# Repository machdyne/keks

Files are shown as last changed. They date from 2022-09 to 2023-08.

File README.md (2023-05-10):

# Keks Game Console

Keks is a 32-bit FPGA-based video game console and computer designed as a fun educational platform for teaching and learning about computers, electronics, FPGAs and programming.

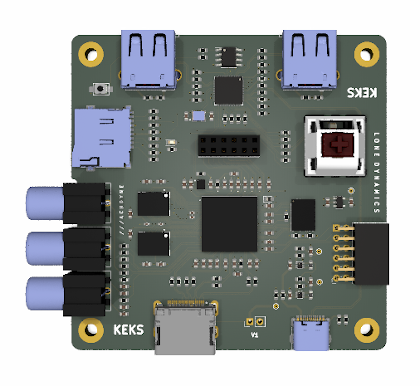
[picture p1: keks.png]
Keks Game Console


This repo contains schematics, PCB layouts, pinouts, firmware, gateware, documentation and a 3D printable case.

Find more information on the [Keks product page](https://machdyne.com/product/keks-game-console/).

## Blinky 

Building the blinky example requires [Yosys](https://github.com/YosysHQ/yosys), [nextpnr-ice40](https://github.com/YosysHQ/nextpnr) and [IceStorm](https://github.com/YosysHQ/icestorm).

Assuming they are installed, you can simply type `make` to build the gateware, which will be written to output/blinky.bin. You can then connect the USB-C port to your computer and use the latest version of [ldprog](https://github.com/machdyne/ldprog) to write the gateware to the device.

## Programming

The RP2040 firmware and FPGA SRAM can be programmed over the USB-C port.

Configure the FPGA SRAM:

```
$ ldprog -k -s blinky.bin
```

It should also be possible to transfer gateware and games to the MicroSD card over the USB-C port but this is not yet implemented.

## Games

* [pong](games/pong)

## Firmware

Keks ships with RP2040 [firmware](firmware) based on the [Müsli](https://github.com/machdyne/musli) firmware which allows it to communicate with [ldprog](https://github.com/machdyne/ldprog).

The firmware is responsible for initializing the system, [configuring and outputting the RP clock](https://www.raspberrypi.com/documentation/pico-sdk/hardware.html#hardware_clocks), configuring the FPGA and detecting USB HID events.

The RP clock (CLK\_RP) is 48MHz by default. Keks also has a 100 MHz oscillator on board (CLK\_100).

*The following description is still under development and may change.*

*If an inserted FAT-formatted MicroSD card contains a bitstream file in the root directory named GATEWARE.BIN it will be used to configure the FPGA after power-on.*

*The RP2040 firmware also acts as an SPI master and sends updates to the FPGA when the status of the gamepads/joysticks change.*

In addition to the 4 CSPI signals and CLK\_RP there are 6 other signals connected to both the RP2040 and the FPGA: RP\_TX, RP\_RX, and RP\_INT, CDONE, CRESET and BTN.

### Updating the Firmware

To build the latest firmware you will need to install the [Raspberry Pi Pico SDK](https://github.com/raspberrypi/pico-sdk).

Set the `PICO_SDK_PATH` environment variable to your SDK path.

```
$ git clone https://github.com/machdyne/keks
$ cd keks/firmware/keks
$ mkdir build
$ cd build
$ cmake ..
$ make
```

The firmware can then be updated by holding down the (small) BOOTSEL button, connecting the USB-C port to your computer, and then dragging and dropping a new UF2 file to the device filesystem.

## DDMI

See this [my_hdmi_device fork](https://github.com/machdyne/my_hdmi_device) for an example of outputting video on the DDMI port.

See this [SmolDVI fork](https://github.com/machdyne/SmolDVI) for another example of outputting video on the DDMI port.

## Pinouts

 * [DDMI](https://github.com/machdyne/ddmi)

## License

The contents of this repo are released under the [Lone Dynamics Open License](LICENSE.md) with the following exceptions:

- The KiCad design files contain parts of the [kicad-pmod](https://github.com/mithro/kicad-pmod) library which is released under the [Apache License, Version 2.0](https://www.apache.org/licenses/LICENSE-2.0.html).

- The KiCad design files may contain symbols and footprints released under other licenses; please contact us if we've failed to give proper attribution.

Note: You can use these designs for commercial purposes but we ask that instead of producing exact clones, that you either replace our trademarks and logos with your own or add your own next to ours.

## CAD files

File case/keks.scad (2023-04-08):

/*
 * Keks Case
 * Copyright (c) 2022 Lone Dynamics Corporation. All rights reserved.
 *
 * required hardware:
 *  - 4 x M3 x 20mm countersunk bolts
 *  - 4 x M3 nuts
 *
 */

$fn = 100;

keks_text = true;

board_width = 80;
board_thickness = 1.5;
board_length = 80;
board_height = 20;
board_spacing = 2;

ldg_board();

translate([0,0,15])
	ldg_case_top();

translate([0,0,-15])
	ldg_case_bottom();

module ldg_board() {
	
	difference() {
		color([0,0.5,0])
			roundedcube(board_width,board_length,board_thickness,3);
		translate([5, 5, -1]) cylinder(d=3.2, h=10);
		translate([5, 75, -1]) cylinder(d=3.2, h=10);
		translate([75, 5, -1]) cylinder(d=3.2, h=10);
		translate([75, 75, -1]) cylinder(d=3.2, h=10);
	}	
	
}

module ldg_case_top() {

	union() {
	
		difference() {

			union () {
			
				color([0.5,0.5,0.5])
					roundedcube(board_width,board_length,13,3);

				translate([-1,27.5,8])
					cube([board_height+60+2,25,6]);
			
			}
	
			translate([1.5,2,-4.8])
				roundedcube(board_width-3,board_length-4,6,3);

			translate([1.5,10,-4])
				roundedcube(board_width-8,board_length-63.7,15,3);
			
			translate([10.5,2,-4])
				roundedcube(board_width-20.5,board_length-4,15,5);

			// LED vent
			translate([28+5,10,10])
				cube([2,10,20]);

			translate([28,10,10])
				cube([2,10,20]);

			translate([28-5,10,10])
				cube([2,10,20]);
			
			// FPGA vent
			translate([45,40-(10/2),10])
				cube([2,10,20]);

			translate([50,40-(10/2),10])
				cube([2,10,20]);

			translate([55,40-(10/2),10])
				cube([2,10,20]);

			// BUTTON
			translate([28.475-(18/2),66.225-(18/2)+0.25,-10]) cube([18,18,50]);
		
			// DDMI
			translate([65,29.05-(16/2),-2]) cube([40,15.5,6+2]);

			// USBC
			translate([65,60.75-(10.5/2)+0.25,-2]) cube([40,10-0.1,3.5+1.75]);

			// PMODA (CART)
			translate([28.4-(7/2)-1.5,40-(20/2),10]) cube([10.5,20,10]);
			translate([28.4-(7/2)+0.5,40-(5/2),10]) cube([11,5,10]);
		
			// PMODB
			translate([55.4-(16/2),75,-2]) cube([16,25,7+1]);
		
			// SD
			translate([26.3-(15/2),-2,-2]) cube([15,30,2+2]);

			// RCA
			translate([53.85-(32.5/2),-2,-3]) cube([32.5,30,13+1.5]);
			
			// USBA HOST
			translate([-2,20-(14.5/2),-0.5]) cube([30,14.5,7.5+1]);
			translate([-2,60-(14.5/2),-0.5]) cube([30,14.5,7.5+1]);
		
			// bolt holes
			translate([5, 5, -21]) cylinder(d=3.5, h=40);
			translate([5, 75, -21]) cylinder(d=3.5, h=40);
			translate([75, 5, -20]) cylinder(d=3.5, h=40);
			translate([75, 75, -21]) cylinder(d=3.5, h=40);

			// flush mount bolt holes
			translate([5, 5, 11.5]) cylinder(d=5.2, h=4);
			translate([5, 75, 11.5]) cylinder(d=5.2, h=4);
			translate([75, 5, 11.5]) cylinder(d=5.2, h=4);
			translate([75, 75, 11.5]) cylinder(d=5.2, h=4);


			// keks text
			if (keks_text) {
				rotate(270)
					translate([-40,10,13])
						linear_extrude(5)
							text("K  E  K  S", size=3.5, halign="center",
								font="Ubuntu:style=Bold");
			}

		}	
	
	}

}

module ldg_case_bottom() {
	
	difference() {
		color([0.5,0.5,0.5])
			roundedcube(board_width,board_length,6,3);
		
		translate([2,10,2])
			roundedcube(board_width-4,board_length-20,8,3);
				
		translate([10,2.5,2])
			roundedcube(board_width-20,board_length-5,8,3);

		// bolt holes
		translate([5, 5, -11]) cylinder(d=3.2, h=25);
		translate([5, 75, -11]) cylinder(d=3.2, h=25);
		translate([75, 5, -11]) cylinder(d=3.2, h=25);
		translate([75, 75, -11]) cylinder(d=3.2, h=25);

		// nut holes
		translate([5, 5, -1.5]) cylinder(d=7, h=4.5, $fn=6);
		translate([5, 75, -1.5]) cylinder(d=7, h=4.5, $fn=6);
		translate([75, 5, -1.5]) cylinder(d=7, h=4.5, $fn=6);
		translate([75, 75, -1.5]) cylinder(d=7, h=4.5, $fn=6);

	}	
}

// https://gist.github.com/tinkerology/ae257c5340a33ee2f149ff3ae97d9826
module roundedcube(xx, yy, height, radius)
{
    translate([0,0,height/2])
    hull()
    {
        translate([radius,radius,0])
        cylinder(height,radius,radius,true);

        translate([xx-radius,radius,0])
        cylinder(height,radius,radius,true);

        translate([xx-radius,yy-radius,0])
        cylinder(height,radius,radius,true);

        translate([radius,yy-radius,0])
        cylinder(height,radius,radius,true);
    }
}

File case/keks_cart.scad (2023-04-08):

/*
 * Keks Cartridge
 * Copyright (c) 2022 Lone Dynamics Corporation. All rights reserved.
 *
 * required hardware:
 *  - 1 x M3 x 12mm countersunk bolt
 *  - 1 x M3 nut
 *  - 1 x MMOD (https://github.com/machdyne/mmod)
 *
 */
 
$fn = 36;
 
cart_height = 26;
cart_width = 19.75;
cart_depth = 10;

notch_width = 4.5;
notch_depth = 2.5;

wall = 1.75;

catch_height = 2;
catch_depth_a = cart_depth - wall - 5.9;
catch_depth_b = 1.5;
catch_pos = 7.25;

lid_height = 1;
lid_insert_height = 9;

translate([0,0,28.5]) color([0.8,0,0])
	cart_lid();

cart();

//translate([0,0,-10])
//	mmod();

module mmod() {
	color([0,1,0])
		cube([16.5,2.5,12.5], center=true);
}

module cart_lid () {
	
	cube([cart_width-wall-1.45,cart_depth-wall-0.1,lid_height], center=true);
	
	difference() {
			
		translate([0,0,-5])
			cube([cart_width-wall-1.45,cart_depth-wall-0.1,lid_insert_height], center=true);
		
		translate([0,0,-16])
			cube([16.6,2.6,lid_insert_height+9], center=true);

		translate([0,-10,-5.5])
			rotate([0,90,90])
				cylinder(d=3.2, h=40);

	}
	
	rotate(0)
		translate([0,-1.25,0])
			linear_extrude(1)
				text("PONG", size=3, halign="center", font="Liberation Sans:style=Bold");

}

module cart() {

	difference() {
		
		union() {
	
			difference() {
		
				cube([cart_width,cart_depth,cart_height], center=true);
			
				translate([0,0,1])
					cube([cart_width-wall-1.35,cart_depth-wall,cart_height+wall+1], center=true);
			
				translate([0,-11,8])
					rotate([0,90,90])
						cylinder(d=5.6, h=40, $fn=36);
	
			}
	
			translate([0,(cart_depth/2)-(catch_depth_a/2)-(wall/2),-(cart_height/2)+(catch_height/2)+catch_pos])
				cube([cart_width, catch_depth_a, catch_height], center=true);

			translate([0,-(cart_depth/2)+(catch_depth_b/2)+(wall/2),-(cart_height/2)+(catch_height/2)+catch_pos])
				cube([cart_width, catch_depth_b, catch_height], center=true);
	
			translate([0,(cart_depth/2)+(notch_depth/2),0])
				cube([notch_width, notch_depth, cart_height], center=true);

			translate([0,(cart_depth/2)+(notch_depth/2),8])
				cube([cart_width, notch_depth, 10], center=true);
	
		}
	
		// nut holes
		translate([0,1,8])
				rotate([0,90,90])
					cylinder(d=7, h=50, $fn=6);
		
	}
	
}

// https://gist.github.com/tinkerology/ae257c5340a33ee2f149ff3ae97d9826
module roundedcube(xx, yy, height, radius)
{
    translate([0,0,height/2])
    hull()
    {
        translate([radius,radius,0])
        cylinder(height,radius,radius,true);

        translate([xx-radius,radius,0])
        cylinder(height,radius,radius,true);

        translate([xx-radius,yy-radius,0])
        cylinder(height,radius,radius,true);

        translate([radius,yy-radius,0])
        cylinder(height,radius,radius,true);
    }
}

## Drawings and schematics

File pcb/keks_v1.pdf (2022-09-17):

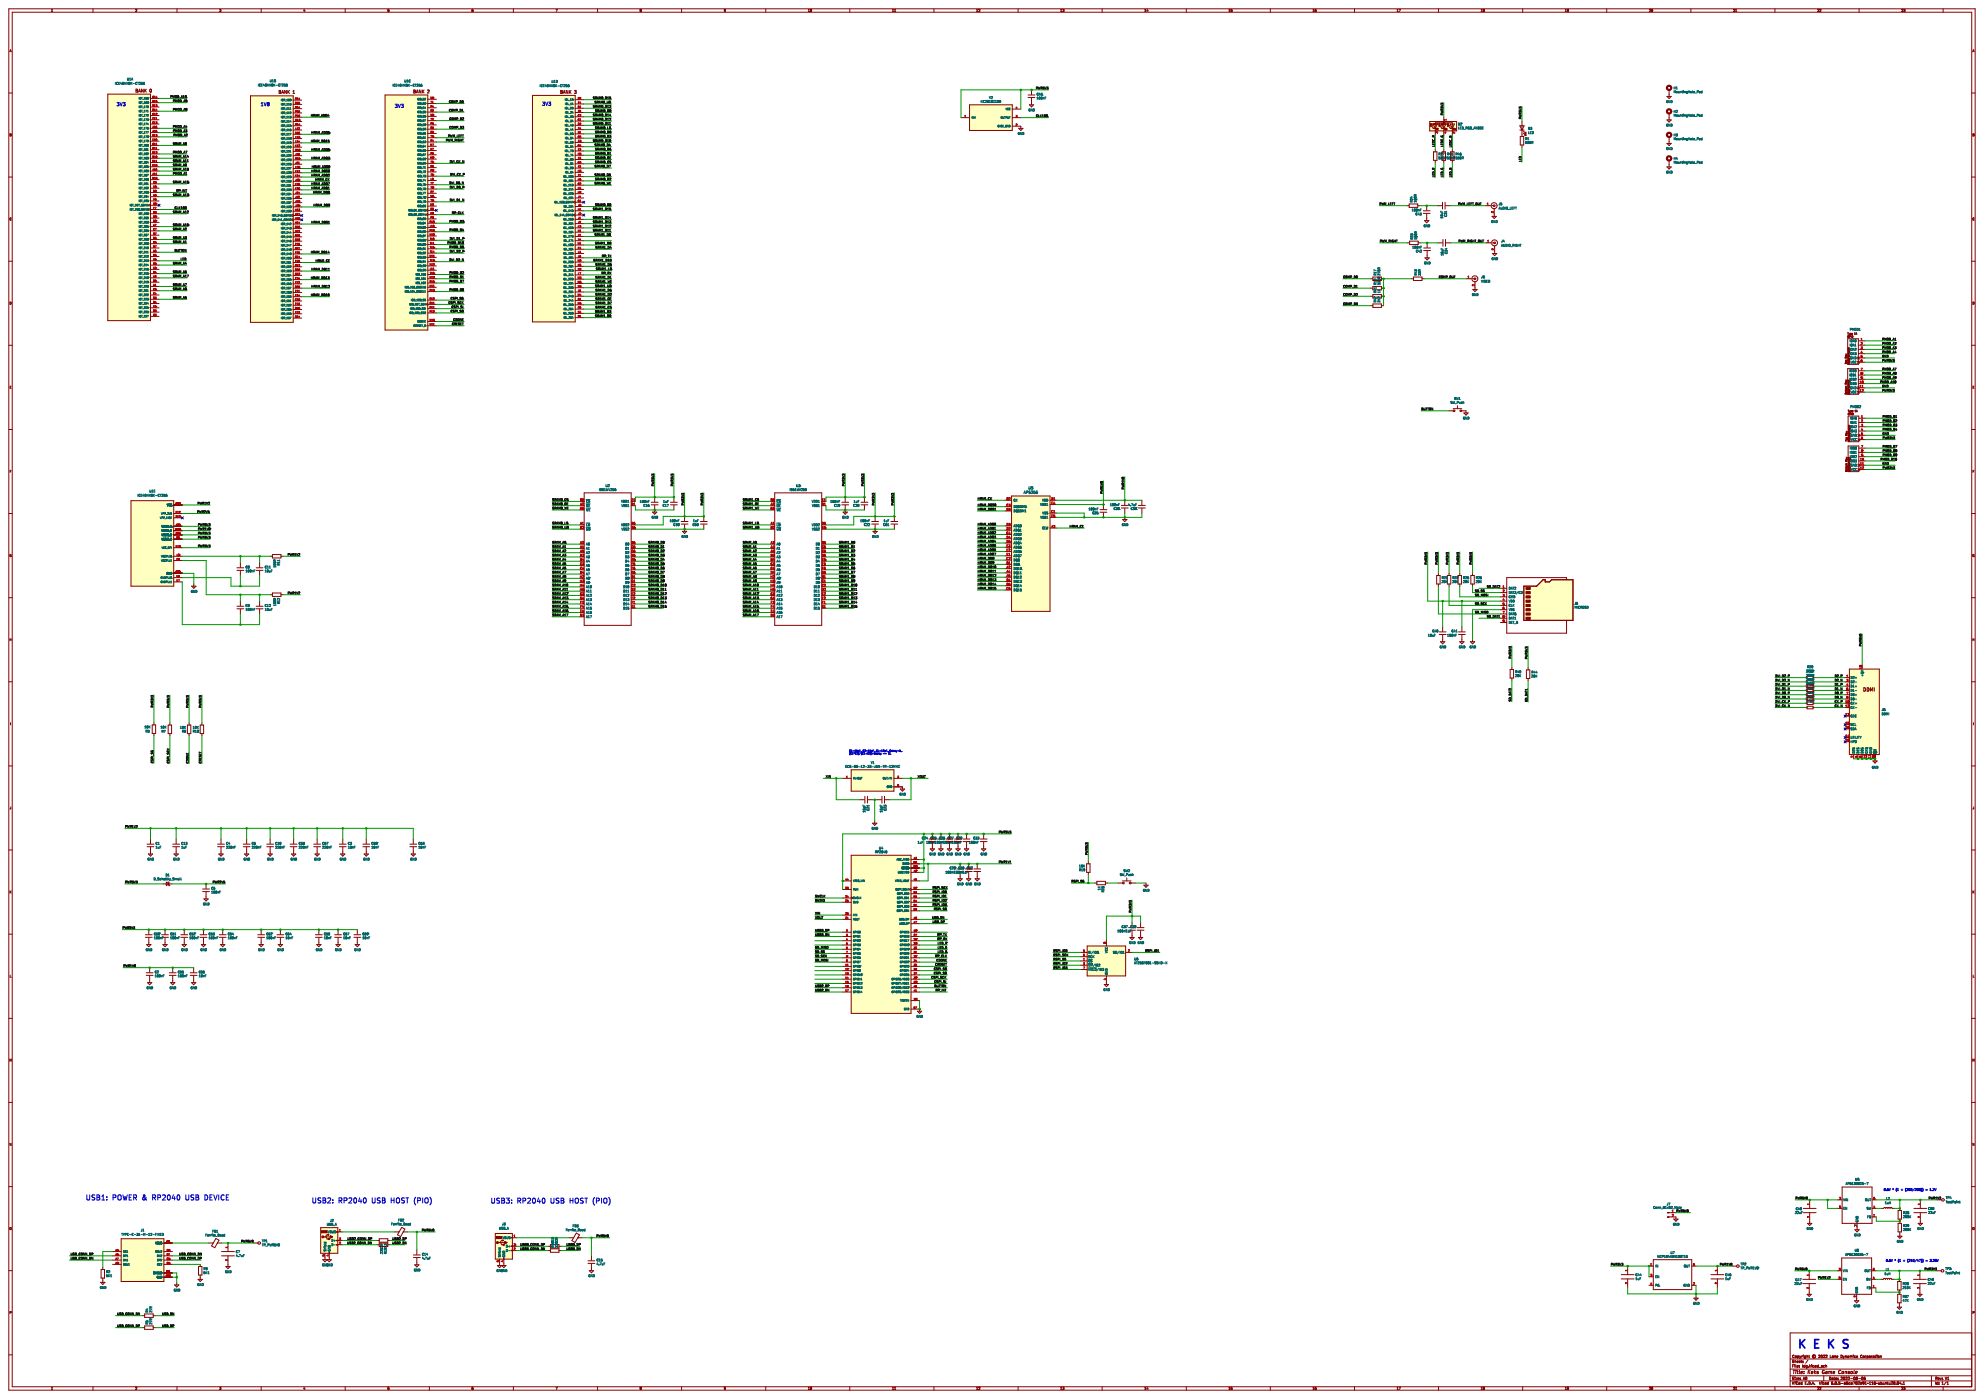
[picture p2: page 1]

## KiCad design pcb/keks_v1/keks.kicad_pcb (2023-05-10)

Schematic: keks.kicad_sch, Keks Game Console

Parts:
C1, C2, C4, C5, C9, C10, C12, C14, C15, C19, C32, C39, C57, C58: 100nF; C_0603_1608Metric
C3, C6, C33, C35, C37, C41, C63, C64: 1uF; C_0603_1608Metric
C7, C34, C36: 100nF; C_0402_1005Metric
C8, C21, C25, C26, C27, C28, C29: 10nF; C_0603_1608Metric
C11, C16, C20, C22, C23: 220nF; C_0603_1608Metric
C13, C30, C31, C56: 4.7uF; R_0603_1608Metric
C17, C18, C60, C61: 10uF; C_0603_1608Metric
C24: 10nF; C_0402_1005Metric
C38, C40: 15pF; C_0603_1608Metric
C42, C49, C55: 1uF; R_0603_1608Metric
C43, C44, C45, C46, C47, C48, C50, C51, C52, C53, C54, C62: 100nF; R_0603_1608Metric
C59: 10uF; R_0603_1608Metric
C65, C66, C67, C68: 22uF; C_0603_1608Metric
D1: D_Schottky_Small; D_0603_1608Metric
D2: LED_RGB_ANODE; LED_RGB_0606_CHANZON
D3: LED; LED_0603_1608Metric
FB1, FB2, FB3: Ferrite_Bead; R_0603_1608Metric
H1, H2, H3, H4: MountingHole_Pad; MountingHole_3.2mm_M3_Pad
J1: TYPE-C-31-M-12-FIXED; USB_C_Receptacle_HRO_TYPE-C-31-M-12-BIG-PADS; PARTREV A
J2, J3: USB_A; USB_A_Stewart_SS-52100-001_Horizontal
J4: VIDEO; Generic_Chinese_RCA_Jack_FIXED
J5: AUDIO_LEFT; Generic_Chinese_RCA_Jack_FIXED
J6: AUDIO_RIGHT; Generic_Chinese_RCA_Jack_FIXED
J7: MICROSD; SDCARD
J8: Conn_01x02_Male; PinHeader_1x02_P2.54mm_Vertical
J9: HDMI_A; HDMI_TE_1827059-3-FIXED
L1, L2: 1uH; L_0603_1608Metric
PMOD1: PMOD-Device-x2-Type-1A-GPIO; PMOD_2x06_HOST_VERTICAL
PMOD2: PMOD-Device-x2-Type-1A-GPIO; PMOD_2x06_HOST
R1, R7: 5K1; R_0603_1608Metric
R2, R3: 27R; R_0603_1608Metric
R4, R5, R6, R8, R16: 10K; R_0603_1608Metric
R9, R10, R22, R23: 100R; R_0603_1608Metric
R11, R12, R13, R14: 22R; R_0603_1608Metric
R15: 1K; R_0402_1005Metric
R17, R20: 1K; R_0603_1608Metric
R18, R35, R36, R37, R38, R39, R40, R41, R42: 270R; R_0603_1608Metric
R19, R25, R27, R29, R33: 536R; R_0603_1608Metric
R21: 2K2; R_0603_1608Metric
R24: 33R; R_0603_1608Metric
R26, R28, R30, R31, R32, R34: 20K; R_0603_1608Metric
R43: 210K; R_0603_1608Metric
R44: 47K; R_0603_1608Metric
R45, R46: 200K; R_0603_1608Metric
SW1: SW_Push; Button_2P_3x4mm
SW2: SW_Push; SW_Cherry_MX_1.00u_PCB
TP1: TP_PWR5V0; TestPoint_THTPad_D1.0mm_Drill0.5mm
TP2, TP3, TP4, TP5, TP6, TP7, TP8, TP9: TestPoint; TestPoint_Pad_1.0x1.0mm
TP10: TP_PWR1V8; TestPoint_THTPad_D1.0mm_Drill0.5mm
TP11, TP12: TestPoint; TestPoint_THTPad_D1.0mm_Drill0.5mm
U1: ICE40HX8K-CT256; BGA256C80P16X16_1400X1400X170; PART_REV 3.4
U2, U3: IS61WV256; BGA48C75P8X6_800X600X120N
U4: RP2040; RP2040-QFN-56-OFFICIAL; PARTREV 1.6.1
U5: APS256; APS256_BGA_24
U6: AT25SF081-SSHD-X; SOIC-8_3.9x4.9mm_P1.27mm
U7: NCP164ASN180T1G; TSOP-5_1.65x3.05mm_P0.95mm
U8, U9: AP61300Z6-7; SOT-563
Y1: ECS-80-12-33-JGN-TR-12MHZ; XTAL_ECS-240-8-33-AGN-TR
Y2: KC2016Z100; OSC_KC2016Z13.5600C1KX00; PARTREV November 2020

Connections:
/BUTTON: SW2.1, U1.A6 (IOT_211), U4.40 (GPIO28/ADC2)
/CDONE: R6.1, U1.M10 (CDONE), U4.34 (GPIO22)
/CK_N: J9.12 (CK-), R42.2
/CK_P: J9.10 (CK+), R41.2
/CLK100: U1.F7 (IOT_198_GBIN0), Y2.3 (OUTPUT)
/COMP_D0: R18.1, U1.T1 (IOB_53)
/COMP_D1: R19.1, U1.R2 (IOB_55)
/COMP_D2: R20.1, U1.T2 (IOB_57)
/COMP_D3: R21.1, U1.R3 (IOB_59)
/COMP_OUT: J4.1 (In), R24.2
/CRESET: R8.1, U1.N11 (CRESET_B), U4.35 (GPIO23)
/CSPI_SCK: R5.1, U1.R11 (IOB_107_SCK), U4.38 (GPIO26/ADC0)
/CSPI_SI: U1.P11 (IOB_106_SDI), U4.39 (GPIO27/ADC1)
/CSPI_SO: U1.P12 (IOB_105_SDO), U4.36 (GPIO24)
/CSPI_SS: R4.1, U1.R12 (IOB_108_SS), U4.37 (GPIO25)
/D0_N: J9.9 (D0-), R40.2
/D0_P: J9.7 (D0+), R39.2
/D1_N: J9.6 (D1-), R38.2
/D1_P: J9.4 (D1+), R37.2
/D2_N: J9.3 (D2-), R36.2
/D2_P: J9.1 (D2+), R35.2
/DVI_CK_N: R42.1, U1.T5 (IOB_69)
/DVI_CK_P: R41.1, U1.T6 (IOB_73)
/DVI_D0_N: R40.1, U1.T7 (IOB_75)
/DVI_D0_P: R39.1, U1.T8 (IOB_76)
/DVI_D1_N: R38.1, U1.T9 (IOB_79)
/DVI_D1_P: R37.1, U1.T10 (IOB_88)
/DVI_D2_N: R36.1, U1.T13 (IOB_94)
/DVI_D2_P: R35.1, U1.T14 (IOB_92)
/HRAM_ADQ0: U1.L16 (IOR_127), U5.D3 (ADQ0)
/HRAM_ADQ1: U1.K16 (IOR_133), U5.D2 (ADQ1)
/HRAM_ADQ2: U1.K14 (IOR_129), U5.C4 (ADQ2)
/HRAM_ADQ3: U1.M15 (IOR_123), U5.D4 (ADQ3)
/HRAM_ADQ4: U1.P16 (IOR_113), U5.D5 (ADQ4)
/HRAM_ADQ5: U1.N16 (IOR_117), U5.E3 (ADQ5)
/HRAM_ADQ6: U1.M16 (IOR_121), U5.E2 (ADQ6)
/HRAM_ADQ7: U1.K15 (IOR_131), U5.E1 (ADQ7)
/HRAM_CE: U1.E16 (IOR_151), U5.A3 (CE#)
/HRAM_CK: U1.J15 (IOR_130), U5.B2 (CK)
/HRAM_DQ8: U1.J14 (IOR_134), U5.C2 (DQ8)
/HRAM_DQ9: U1.J16 (IOR_138), U5.B1 (DQ9)
/HRAM_DQ10: U1.E14 (IOR_160), U5.A2 (DQ10)
/HRAM_DQ11: U1.D16 (IOR_153), U5.A4 (DQ11)
/HRAM_DQ12: U1.D15 (IOR_157), U5.A5 (DQ12)
/HRAM_DQ13: U1.F14 (IOR_155), U5.B4 (DQ13)
/HRAM_DQ14: U1.F15 (IOR_149), U5.B5 (DQ14)
/HRAM_DQ15: U1.L14 (IOR_119), U5.C5 (DQ15)
/HRAM_DQS0: U1.K13 (IOR_128), U5.C3 (DQSDM0)
/HRAM_DQS1: U1.H14 (IOR_142), U5.B3 (DQSDM1)
/LED: R33.2, U1.A5 (IOT_213)
/LEDC_B: D2.2 (BK), R29.1
/LEDC_G: D2.4 (GK), R27.1
/LEDC_R: D2.3 (RK), R25.1
/LED_B: R29.2, U4.31 (GPIO20)
/LED_G: R27.2, U4.30 (GPIO19)
/LED_R: R25.2, U4.29 (GPIO18)
/PMOD_A1: PMOD1.1 (IOA0), U1.A11 (IOT_187)
/PMOD_A2: PMOD1.2 (IOA1), U1.B13 (IOT_178)
/PMOD_A3: PMOD1.3 (IOA2), U1.A15 (IOT_177)
/PMOD_A4: PMOD1.4 (IOA3), U1.A16 (IOT_176)
/PMOD_A7: PMOD1.7 (IOB0), U1.B12 (IOT_182)
/PMOD_A8: PMOD1.8 (IOB1), U1.B14 (IOT_171)
/PMOD_A9: PMOD1.9 (IOB2), U1.B15 (IOT_169)
/PMOD_A10: PMOD1.10 (IOB3), U1.C14 (IOT_168)
/PMOD_B1: PMOD2.1 (IOA0), U1.M12 (IOB_101)
/PMOD_B2: PMOD2.2 (IOA1), U1.T16 (IOB_100)
/PMOD_B3: PMOD2.3 (IOA2), U1.R10 (IOB_84)
/PMOD_B4: PMOD2.4 (IOA3), U1.P10 (IOB_86)
/PMOD_B7: PMOD2.7 (IOB0), U1.R16 (IOB_102)
/PMOD_B8: PMOD2.8 (IOB1), U1.T15 (IOB_91)
/PMOD_B9: PMOD2.9 (IOB2), U1.P13 (IOB_104_CBSEL1)
/PMOD_B10: PMOD2.10 (IOB3), U1.T11 (IOB_89)
/PWM_LEFT: R22.1, U1.T3 (IOB_61)
/PWM_LEFT_OUT: C60.1, J5.1 (In)
/PWM_RIGHT: R23.1, U1.R4 (IOB_63)
/PWM_RIGHT_OUT: C61.1, J6.1 (In)
/PWR1V1: C46.1, C48.1, C49.1, U4.23 (DVDD), U4.45 (VREG_VOUT), U4.50 (DVDD)
/PWR1V2: C3.1, C6.1, C11.1, C16.1, C20.1, C22.1, C23.1, C26.1, C28.1, C29.1, C68.1, L2.2, R9.1, R10.1, R45.1, TP12.1, U1.A14 (VCC), U1.F6 (VCC), U1.F10 (VCC), U1.K6 (VCC), U1.K10 (VCC), U1.L2 (VCC), U8.5 (EN), U9.6 (OUT)
/PWR1V8: C2.1, C5.1, C8.1, C52.2, C53.2, C56.2, C64.1, TP10.1, U1.C15 (VCCIO_1), U1.H10 (VCCIO_1), U1.H15 (VCCIO_1), U1.N15 (VCCIO_1), U5.D1 (VDD), U5.E4 (VDD1), U7.5 (OUT)
/PWR2V5: C10.1, D1.1 (K), U1.E12 (VPP_2V5)
/PWR3V3: C1.1, C4.1, C7.1, C9.1, C12.1, C19.1, C21.1, C24.1, C25.1, C27.1, C32.2, C33.2, C34.2, C35.2, C36.2, C37.2, C39.2, C41.2, C42.1, C43.1, C44.1, C45.1, C47.1, C50.1, C51.1, C54.1, C55.1, C59.1, C62.1, C63.1, C67.1, D1.2 (A), D2.1 (A), D3.2 (A), J7.4 (VDD), L1.2, PMOD1.6 (VCC), PMOD1.12 (VCC), PMOD2.6 (VCC), PMOD2.12 (VCC), R4.2, R5.2, R6.2, R8.2, R16.2, R26.1, R28.1, R30.1, R31.1, R32.1, R34.1, R43.1, TP11.1, U1.A3 (VCCIO_0), U1.A8 (VCCIO_0), U1.A13 (VCCIO_0), U1.E1 (VCCIO_3), U1.F8 (VCCIO_0), U1.G6 (VCCIO_3), U1.J6 (VCCIO_3), U1.K8 (VCCIO_2), U1.N1 (VCCIO_3), U1.N13 (VCC_SPI), U1.P3 (VCCIO_2), U1.R8 (VCCIO_2), U1.R13 (VCCIO_2), U2.D6 (VDD2), U2.E1 (VDD1), U3.D6 (VDD2), U3.E1 (VDD1), U4.1 (IOVDD), U4.10 (IOVDD), U4.22 (IOVDD), U4.26 (RUN), U4.33 (IOVDD), U4.42 (IOVDD), U4.43 (ADC_AVDD), U4.44 (VREG_VIN), U4.48 (USB_VDD), U4.49 (IOVDD), U6.8 (VCC), U7.1 (IN), U7.3 (EN), U8.6 (OUT), Y2.1 (INH), Y2.4 (VCC)
/PWR5V0: C13.1, C30.1, C31.1, C65.1, C66.1, FB1.1, FB2.1, FB3.1, J8.1, J9.18 (+5V), TP1.1, U8.3 (VIN), U9.3 (VIN), U9.5 (EN)
/RP_CLK: U1.K9 (IOB_82_GBIN4), U4.32 (GPIO21)
/RP_INT: U1.D9 (IOT_193), U4.41 (GPIO29/ADC3)
/RP_RX: U1.L7 (IOL_21A), U4.28 (GPIO17)
/RP_TX: U1.L6 (IOL_19A), U4.27 (GPIO16)
/RSPI_IO0: TP5.1, U4.53 (QSPI_SD0), U6.5 (SI/IO0)
/RSPI_IO1: TP6.1, U4.55 (QSPI_SD1), U6.2 (SO/IO1)
/RSPI_IO2: TP7.1, U4.54 (QSPI_SD2), U6.3 (~WP/IO2)
/RSPI_IO3: TP8.1, U4.51 (QSPI_SD3), U6.7 (~HOLD/IO3)
/RSPI_SCK: TP9.1, U4.52 (QSPI_SCLK), U6.6 (SCK)
/RSPI_SS: R16.1, R17.2, TP4.1, U4.56 (QSPI_CSN), U6.1 (~CS)
/SD_DAT1: J7.8 (DAT1), R34.2
/SD_DAT2: J7.1 (DAT2), R32.2
/SD_MISO: J7.7 (DAT0), R26.2, U4.6 (GPIO4)
/SD_MOSI: J7.3 (CMD), R30.2, U4.9 (GPIO7)
/SD_SCK: J7.5 (CLK), R28.2, U4.8 (GPIO6)
/SD_SS: J7.2 (DAT3/CD), R31.2, U4.7 (GPIO5)
/SRAM0_CS: U1.G3 (IOL_8A), U2.B5 (~CS)
/SRAM0_D0: U1.J5 (IOL_13A), U2.B6 (D0)
/SRAM0_D1: U1.H5 (IOL_7A), U2.C5 (D1)
/SRAM0_D2: U1.H6 (IOL_10A), U2.C6 (D2)
/SRAM0_D3: U1.G5 (IOL_5A), U2.D5 (D3)
/SRAM0_D4: U1.G4 (IOL_6A), U2.E5 (D4)
/SRAM0_D5: U1.F1 (IOL_10B), U2.F5 (D5)
/SRAM0_D6: U1.E2 (IOL_7B), U2.F6 (D6)
/SRAM0_D7: U1.F2 (IOL_9B), U2.G6 (D7)
/SRAM0_D8: U1.F5 (IOL_2A), U2.B1 (D8)
/SRAM0_D9: U1.D1 (IOL_5B), U2.C1 (D9)
/SRAM0_D10: U1.E3 (IOL_6B), U2.C2 (D10)
/SRAM0_D11: U1.D2 (IOL_4B), U2.D2 (D11)
/SRAM0_D12: U1.C1 (IOL_3A), U2.E2 (D12)
/SRAM0_D13: U1.B1 (IOL_2B), U2.F2 (D13)
/SRAM0_D14: U1.C2 (IOL_3B), U2.F1 (D14)
/SRAM0_D15: U1.B2 (IOL_1B), U2.G1 (D15)
/SRAM0_LB: U1.F4 (IOL_4A), U2.A1 (~LB)
/SRAM0_OE: U1.F3 (IOL_8B), U2.A2 (~OE)
/SRAM0_UB: U1.E4 (IOL_1A), U2.B2 (~UB)
/SRAM0_WE: U1.G2 (IOL_11B), U2.G5 (~WE)
/SRAM1_CS: U1.P2 (IOL_25A), U3.B5 (~CS)
/SRAM1_D0: U1.R1 (IOL_26A), U3.B6 (D0)
/SRAM1_D1: U1.M3 (IOL_22B), U3.C5 (D1)
/SRAM1_D2: U1.M4 (IOL_24B), U3.C6 (D2)
/SRAM1_D3: U1.N4 (IOL_26B), U3.D5 (D3)
/SRAM1_D4: U1.K4 (IOL_18A), U3.E5 (D4)
/SRAM1_D5: U1.K5 (IOL_20A), U3.F5 (D5)
/SRAM1_D6: U1.L5 (IOL_23A), U3.F6 (D6)
/SRAM1_D7: U1.M5 (IOL_25B), U3.G6 (D7)
/SRAM1_D8: U1.M1 (IOL_18B), U3.B1 (D8)
/SRAM1_D9: U1.L1 (IOL_17B), U3.C1 (D9)
/SRAM1_D10: U1.M2 (IOL_20B), U3.C2 (D10)
/SRAM1_D11: U1.K1 (IOL_16A), U3.D2 (D11)
/SRAM1_D12: U1.K3 (IOL_16B), U3.E2 (D12)
/SRAM1_D13: U1.J2 (IOL_15A), U3.F2 (D13)
/SRAM1_D14: U1.J1 (IOL_15B), U3.F1 (D14)
/SRAM1_D15: U1.H1 (IOL_14B), U3.G1 (D15)
/SRAM1_LB: U1.N2 (IOL_21B), U3.A1 (~LB)
/SRAM1_OE: U1.P1 (IOL_24A), U3.A2 (~OE)
/SRAM1_UB: U1.N3 (IOL_23B), U3.B2 (~UB)
/SRAM1_WE: U1.M6 (IOL_22A), U3.G5 (~WE)
/SRAM_A0: U1.C5 (IOT_221), U2.A3 (A0), U3.A3 (A0)
/SRAM_A1: U1.C6 (IOT_209), U2.A4 (A1), U3.A4 (A1)
/SRAM_A2: U1.C7 (IOT_206), U2.A5 (A2), U3.A5 (A2)
/SRAM_A3: U1.B6 (IOT_208), U2.B3 (A3), U3.B3 (A3)
/SRAM_A4: U1.B5 (IOT_214), U2.B4 (A4), U3.B4 (A4)
/SRAM_A5: U1.B4 (IOT_216), U2.C3 (A5), U3.C3 (A5)
/SRAM_A6: U1.B3 (IOT_223), U2.C4 (A6), U3.C4 (A6)
/SRAM_A7: U1.A1 (IOT_220), U2.D4 (A7), U3.D4 (A7)
/SRAM_A8: U1.C10 (IOT_185), U2.H2 (A8), U3.H2 (A8)
/SRAM_A9: U1.C11 (IOT_180), U2.H3 (A9), U3.H3 (A9)
/SRAM_A10: U1.A10 (IOT_186), U2.H4 (A10), U3.H4 (A10)
/SRAM_A11: U1.B11 (IOT_184), U2.H5 (A11), U3.H5 (A11)
/SRAM_A12: U1.B9 (IOT_199), U2.G3 (A12), U3.G3 (A12)
/SRAM_A13: U1.A9 (IOT_194), U2.G4 (A13), U3.G4 (A13)
/SRAM_A14: U1.B10 (IOT_183), U2.F3 (A14), U3.F3 (A14)
/SRAM_A15: U1.C9 (IOT_191), U2.F4 (A15), U3.F4 (A15)
/SRAM_A16: U1.A7 (IOT_205), U2.E4 (A16), U3.E4 (A16)
/SRAM_A17: U1.A2 (IOT_218), U2.D3 (A17), U3.D3 (A17)
/SWCLK: TP2.1, U4.24 (SWCLK)
/SWDIO: TP3.1, U4.25 (SWD)
/USB2_CONN_DN: J2.2 (D-), R12.2
/USB2_CONN_DP: J2.3 (D+), R11.2
/USB2_DN: R12.1, U4.17 (GPIO14)
/USB2_DP: R11.1, U4.16 (GPIO13)
/USB3_CONN_DN: J3.2 (D-), R14.1
/USB3_CONN_DP: J3.3 (D+), R13.1
/USB3_DN: R14.2, U4.3 (GPIO1)
/USB3_DP: R13.2, U4.2 (GPIO0)
/USB_CONN_DN: J1.A7 (DN1), J1.B7 (DN2), R2.1
/USB_CONN_DP: J1.A6 (DP1), J1.B6 (DP2), R3.1
/USB_DN: R2.2, U4.46 (USB_DM)
/USB_DP: R3.2, U4.47 (USB_DP)
/XIN: C38.2, U4.20 (XIN), Y1.1 (IN/OUT)
/XOUT: R15.1, U4.21 (XOUT)
GND: C1.2, C2.2, C3.2, C4.2, C5.2, C6.2, C7.2, C8.2, C9.2, C10.2, C11.2, C12.2, C13.2, C16.2, C19.2, C20.2, C21.2, C22.2, C23.2, C24.2, C25.2, C26.2, C27.2, C28.2, C29.2, C30.2, C31.2, C32.1, C33.1, C34.1, C35.1, C36.1, C37.1, C38.1, C39.1, C40.2, C41.1, C42.2, C43.2, C44.2, C45.2, C46.2, C47.2, C48.2, C49.2, C50.2, C51.2, C52.1, C53.1, C54.2, C55.2, C56.1, C57.1, C58.1, C59.2, C62.2, C63.2, C64.2, C65.2, C66.2, C67.2, C68.2, H1.1, H2.1, H3.1, H4.1, J1.A1 (GND), J1.A12 (GND), J1.B1 (GND), J1.B12 (GND), J1.S1 (SHIELD), J1.S2 (SHIELD), J1.S3 (SHIELD), J1.S4 (SHIELD), J2.4 (GND), J2.5 (Shield), J3.4 (GND), J3.5 (Shield), J4.2 (Ext), J5.2 (Ext), J6.2 (Ext), J7.6 (VSS), J8.2, J9.2 (D2S), J9.5 (D1S), J9.8 (D0S), J9.11 (CKS), J9.17 (GND), J9.S1 (SH), J9.S2 (SH), J9.S3 (SH), J9.S4 (SH), PMOD1.5 (GND), PMOD1.11 (GND), PMOD2.5 (GND), PMOD2.11 (GND), R1.2, R7.2, R44.2, R46.2, SW1.2, SW2.2, U1.A4 (GND), U1.A12 (GND), U1.E15 (GND), U1.G7 (GND), U1.G8 (GND), U1.G9 (GND), U1.H7 (GND), U1.H8 (GND), U1.H9 (GND), U1.J7 (GND), U1.J8 (GND), U1.J9 (GND), U1.K2 (GND), U1.K7 (GND), U1.L15 (GND), U1.R7 (GND), U1.T4 (GND), U1.T12 (GND), U2.D1 (VSS1), U2.E6 (VSS2), U3.D1 (VSS1), U3.E6 (VSS2), U4.19 (TESTEN), U4.57 (GND), U5.C1 (VSS), U5.E5 (VSS1), U6.4 (GND), U7.2 (GND), U8.2 (GND), U9.2 (GND), Y1.2 (GND), Y1.4 (GND), Y2.2 (CASE_GND)
unnamed: C14.1, C17.1, R9.2, U1.L8 (VCCPLL0)
unnamed: C14.2, C17.2, U1.N8 (GNDPLL0)
unnamed: C15.1, C18.1, R10.2, U1.E8 (VCCPLL1)
unnamed: C15.2, C18.2, U1.E7 (GNDPLL1)
unnamed: C40.1, R15.2, Y1.3 (OUT/IN)
unnamed: C57.2, C60.2, R22.2
unnamed: C58.2, C61.2, R23.2
unnamed: D3.1 (K), R33.1
unnamed: FB1.2, J1.A4 (VBUS), J1.A9 (VBUS), J1.B4 (VBUS), J1.B9 (VBUS)
unnamed: FB2.2, J2.1 (VBUS)
unnamed: FB3.2, J3.1 (VBUS)
unnamed: J1.A5 (CC1), R1.1
unnamed: J1.B5 (CC2), R7.1
unnamed: L1.1, U8.4 (SW)
unnamed: L2.1, U9.4 (SW)
unnamed: R17.1, SW1.1
unnamed: R18.2, R19.2, R20.2, R21.2, R24.1
unnamed: R43.2, R44.1, U8.1 (FB)
unnamed: R45.2, R46.1, U9.1 (FB)

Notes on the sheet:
3V3
USB3: RP2040 USB HOST (PIO)
0.6V * (1 + (210/47)) = 3.28V
C1=15pF, C2=15pF, CL=12pF, Cstray=5, (C1*C2)/(C1+C2)+Cstray == CL
0.6V * (1 + (200/200)) = 1.2V
K E K S
1V8
USB2: RP2040 USB HOST (PIO)
USB1: POWER & RP2040 USB DEVICE

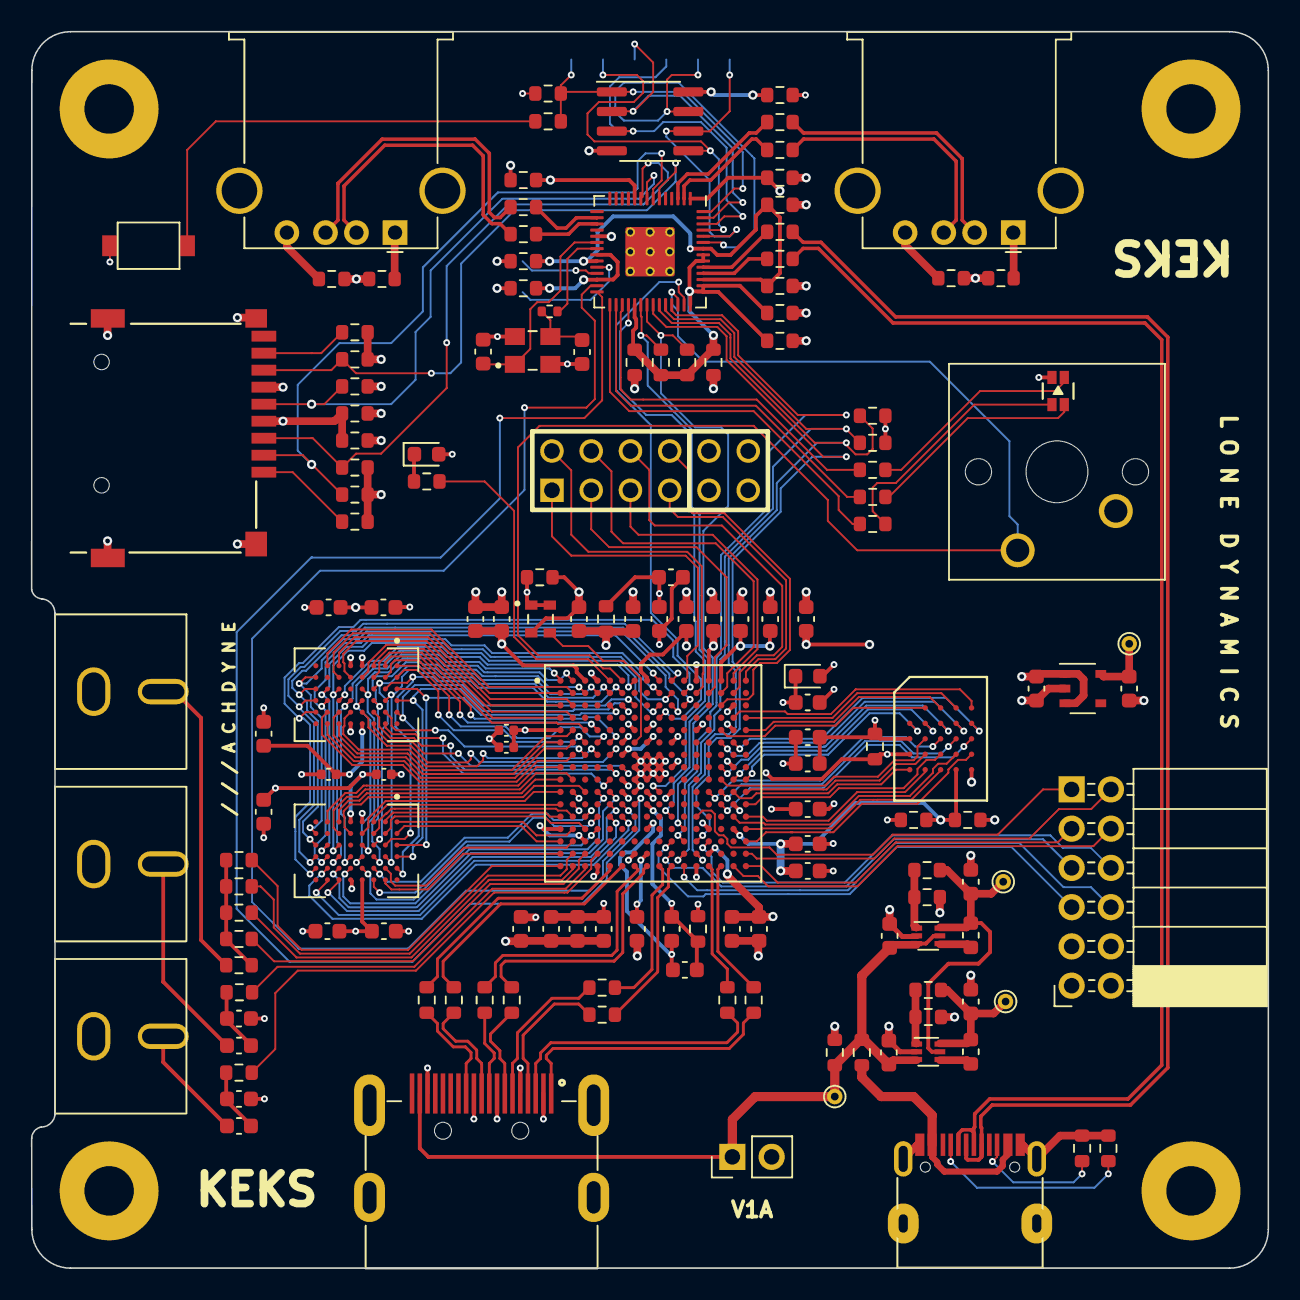
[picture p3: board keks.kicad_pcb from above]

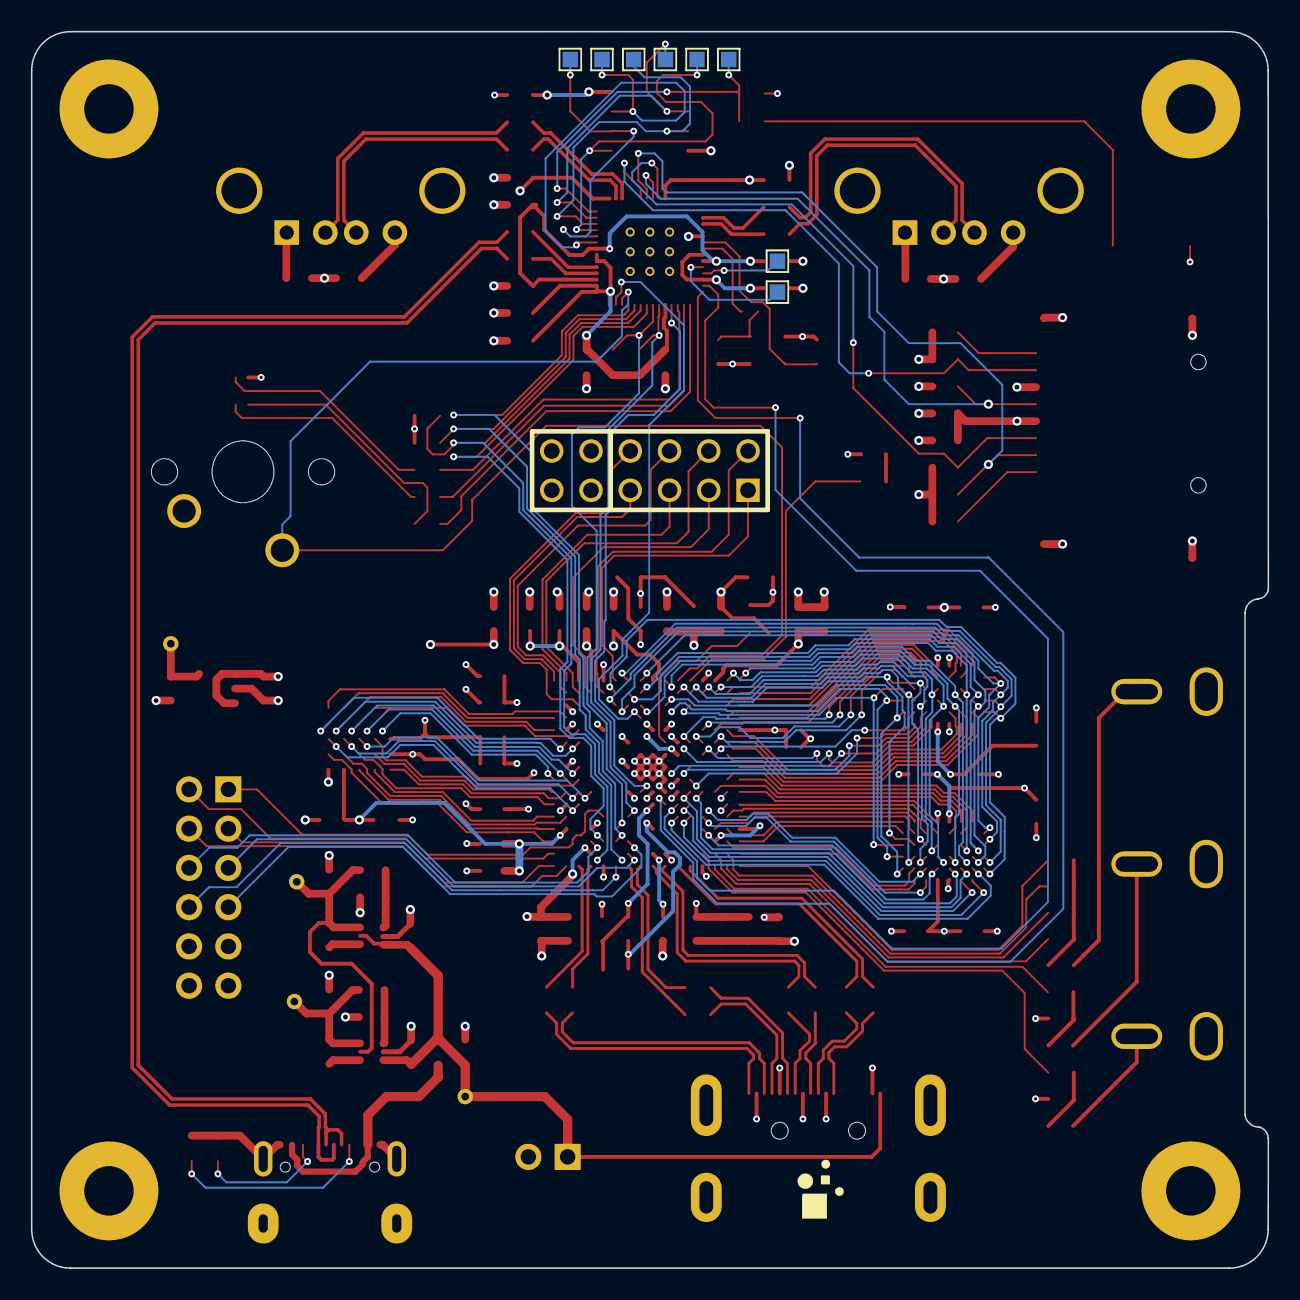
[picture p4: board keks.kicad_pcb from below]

Board: 4 copper layers, 80.0 x 80.0 mm, 162 parts (8 on the bottom side), 194 nets.

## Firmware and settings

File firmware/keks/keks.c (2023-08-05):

/**
 * Copyright (c) 2020 Raspberry Pi (Trading) Ltd.
 * Copyright (c) 2022 Lone Dynamics Corporation <info@lonedynamics.com>
 *
 * SPDX-License-Identifier: BSD-3-Clause
 *
 * Keks Firmware (work-in-progress)
 *
 */

#include <stdio.h>
#include <stdlib.h>
#include <strings.h>
#include <string.h>

#include "pico/stdlib.h"
#include "pico/stdio.h"
#include "hardware/uart.h"
#include "hardware/spi.h"
#include "hardware/pio.h"
#include "hardware/watchdog.h"
#include "hardware/pll.h"
#include "hardware/clocks.h"
#include "hardware/structs/pll.h"
#include "hardware/structs/clocks.h"
#include "pico/stdlib.h"
#include "pico/binary_info.h"
#include "pico/multicore.h"
#include "pico/bootrom.h"

#include "pio_usb.h"
#include "spi_slave_tx.pio.h"
#include "spi_slave_rx.pio.h"
#include "spi_master_tx.pio.h"
#include "keks.h"
#include "fs.h"

// Include descriptor struct definitions
#include "usb_common.h"
// USB register definitions from pico-sdk
#include "hardware/regs/usb.h"
// USB hardware struct definitions from pico-sdk
#include "hardware/structs/usb.h"
// For interrupt enable and numbers
#include "hardware/irq.h"
// For resetting the USB controller
#include "hardware/resets.h"

// Device descriptors
#include "keks_usb.h"

// spi_master and spi_slave PIO is shared with pico-pio-usb
#define SPI_SLAVE_RX_PIO pio0
#define SPI_SLAVE_RX_SM 1
#define SPI_SLAVE_TX_PIO pio0
#define SPI_SLAVE_TX_SM 2
#define SPI_MASTER_TX_PIO pio0
#define SPI_MASTER_TX_SM 3

void pio_spi_slave_write8_blocking(PIO pio, uint sm, const uint8_t *src, size_t len);
void pio_spi_master_write8_blocking(PIO pio, uint sm, const uint8_t *src, size_t len);

void init_ldprog(void);
void init_keks(void);
void init_keks_postconf(void);
int rptcmp(char *a, char *b, int len);
void set_rgb_led(int r, int g, int b);
void gpio_int(uint gpio, uint32_t events);
void core1_main();

bool keks_fpga_configured = false;

static usb_device_t *usb_host_device = NULL;

#define usb_hw_set hw_set_alias(usb_hw)
#define usb_hw_clear hw_clear_alias(usb_hw)

// Function prototypes for our device specific endpoint handlers defined
// later on
void ep0_in_handler(uint8_t *buf, uint16_t len);
void ep0_out_handler(uint8_t *buf, uint16_t len);
void ep1_out_handler(uint8_t *buf, uint16_t len);
void ep2_in_handler(uint8_t *buf, uint16_t len);

// Global device address
static bool should_set_address = false;
static uint8_t dev_addr = 0;
static volatile bool usb_configured = false;

// Global data buffer for EP0
static uint8_t ep0_buf[64];

// Struct defining the device configuration
static struct usb_device_configuration dev_config = {
        .device_descriptor = &device_descriptor,
        .interface_descriptor = &interface_descriptor,
        .config_descriptor = &config_descriptor,
        .lang_descriptor = lang_descriptor,
        .descriptor_strings = descriptor_strings,
        .endpoints = {
                {
                        .descriptor = &ep0_out,
                        .handler = &ep0_out_handler,
                        .endpoint_control = NULL, // NA for EP0
                        .buffer_control = &usb_dpram->ep_buf_ctrl[0].out,
                        // EP0 in and out share a data buffer
                        .data_buffer = &usb_dpram->ep0_buf_a[0],
                },
                {
                        .descriptor = &ep0_in,
                        .handler = &ep0_in_handler,
                        .endpoint_control = NULL, // NA for EP0,
                        .buffer_control = &usb_dpram->ep_buf_ctrl[0].in,
                        // EP0 in and out share a data buffer
                        .data_buffer = &usb_dpram->ep0_buf_a[0],
                },
                {
                        .descriptor = &ep1_out,
                        .handler = &ep1_out_handler,
                        // EP1 starts at offset 0 for endpoint control
                        .endpoint_control = &usb_dpram->ep_ctrl[0].out,
                        .buffer_control = &usb_dpram->ep_buf_ctrl[1].out,
                        // First free EPX buffer
                        .data_buffer = &usb_dpram->epx_data[0 * 64],
                },
                {
                        .descriptor = &ep2_in,
                        .handler = &ep2_in_handler,
                        .endpoint_control = &usb_dpram->ep_ctrl[1].in,
                        .buffer_control = &usb_dpram->ep_buf_ctrl[2].in,
                        // Second free EPX buffer
                        .data_buffer = &usb_dpram->epx_data[1 * 64],
                }
        }
};

/**
 * @brief Given an endpoint address, return the usb_endpoint_configuration of that endpoint. Returns NULL
 * if an endpoint of that address is not found.
 *
 * @param addr
 * @return struct usb_endpoint_configuration*
 */
struct usb_endpoint_configuration *usb_get_endpoint_configuration(uint8_t addr) {
    struct usb_endpoint_configuration *endpoints = dev_config.endpoints;
    for (int i = 0; i < USB_NUM_ENDPOINTS; i++) {
        if (endpoints[i].descriptor && (endpoints[i].descriptor->bEndpointAddress == addr)) {
            return &endpoints[i];
        }
    }
    return NULL;
}

/**
 * @brief Given a C string, fill the EP0 data buf with a USB string descriptor for that string.
 *
 * @param C string you would like to send to the USB host
 * @return the length of the string descriptor in EP0 buf
 */
uint8_t usb_prepare_string_descriptor(const unsigned char *str) {
    // 2 for bLength + bDescriptorType + strlen * 2 because string is unicode. i.e. other byte will be 0
    uint8_t bLength = 2 + (strlen((const char *)str) * 2);
    static const uint8_t bDescriptorType = 0x03;

    volatile uint8_t *buf = &ep0_buf[0];
    *buf++ = bLength;
    *buf++ = bDescriptorType;

    uint8_t c;

    do {
        c = *str++;
        *buf++ = c;
        *buf++ = 0;
    } while (c != '\0');

    return bLength;
}

/**
 * @brief Take a buffer pointer located in the USB RAM and return as an offset of the RAM.
 *
 * @param buf
 * @return uint32_t
 */
static inline uint32_t usb_buffer_offset(volatile uint8_t *buf) {
    return (uint32_t) buf ^ (uint32_t) usb_dpram;
}

/**
 * @brief Set up the endpoint control register for an endpoint (if applicable. Not valid for EP0).
 *
 * @param ep
 */
void usb_setup_endpoint(const struct usb_endpoint_configuration *ep) {
    printf("Set up endpoint 0x%x with buffer address 0x%p\n", ep->descriptor->bEndpointAddress, ep->data_buffer);

    // EP0 doesn't have one so return if that is the case
    if (!ep->endpoint_control) {
        return;
    }

    // Get the data buffer as an offset of the USB controller's DPRAM
    uint32_t dpram_offset = usb_buffer_offset(ep->data_buffer);
    uint32_t reg = EP_CTRL_ENABLE_BITS
                   | EP_CTRL_INTERRUPT_PER_BUFFER
                   | (ep->descriptor->bmAttributes << EP_CTRL_BUFFER_TYPE_LSB)
                   | dpram_offset;
    *ep->endpoint_control = reg;
}

/**
 * @brief Set up the endpoint control register for each endpoint.
 *
 */
void usb_setup_endpoints() {
    const struct usb_endpoint_configuration *endpoints = dev_config.endpoints;
    for (int i = 0; i < USB_NUM_ENDPOINTS; i++) {
        if (endpoints[i].descriptor && endpoints[i].handler) {
            usb_setup_endpoint(&endpoints[i]);
        }
    }
}

/**
 * @brief Set up the USB controller in device mode, clearing any previous state.
 *
 */
void usb_device_init() {
    // Reset usb controller
    reset_block(RESETS_RESET_USBCTRL_BITS);
    unreset_block_wait(RESETS_RESET_USBCTRL_BITS);

    // Clear any previous state in dpram just in case
    memset(usb_dpram, 0, sizeof(*usb_dpram)); // <1>

    // Enable USB interrupt at processor
    irq_set_enabled(USBCTRL_IRQ, true);

    // Mux the controller to the onboard usb phy
    usb_hw->muxing = USB_USB_MUXING_TO_PHY_BITS | USB_USB_MUXING_SOFTCON_BITS;

    // Force VBUS detect so the device thinks it is plugged into a host
    usb_hw->pwr = USB_USB_PWR_VBUS_DETECT_BITS | USB_USB_PWR_VBUS_DETECT_OVERRIDE_EN_BITS;

    // Enable the USB controller in device mode.
    usb_hw->main_ctrl = USB_MAIN_CTRL_CONTROLLER_EN_BITS;

    // Enable an interrupt per EP0 transaction
    usb_hw->sie_ctrl = USB_SIE_CTRL_EP0_INT_1BUF_BITS; // <2>

    // Enable interrupts for when a buffer is done, when the bus is reset,
    // and when a setup packet is received
    usb_hw->inte = USB_INTS_BUFF_STATUS_BITS |
                   USB_INTS_BUS_RESET_BITS |
                   USB_INTS_SETUP_REQ_BITS;

    // Set up endpoints (endpoint control registers)
    // described by device configuration
    usb_setup_endpoints();

    // Present full speed device by enabling pull up on DP
    usb_hw_set->sie_ctrl = USB_SIE_CTRL_PULLUP_EN_BITS;
}

/**
 * @brief Given an endpoint configuration, returns true if the endpoint
 * is transmitting data to the host (i.e. is an IN endpoint)
 *
 * @param ep, the endpoint configuration
 * @return true
 * @return false
 */
static inline bool ep_is_tx(struct usb_endpoint_configuration *ep) {
    return ep->descriptor->bEndpointAddress & USB_DIR_IN;
}

/**
 * @brief Starts a transfer on a given endpoint.
 *
 * @param ep, the endpoint configuration.
 * @param buf, the data buffer to send. Only applicable if the endpoint is TX
 * @param len, the length of the data in buf (this example limits max len to one packet - 64 bytes)
 */
void usb_start_transfer(struct usb_endpoint_configuration *ep, uint8_t *buf, uint16_t len) {
    // We are asserting that the length is <= 64 bytes for simplicity of the example.
    // For multi packet transfers see the tinyusb port.
    assert(len <= 64);

//    printf("Start transfer of len %d on ep addr 0x%x\n", len, ep->descriptor->bEndpointAddress);

    // Prepare buffer control register value
    uint32_t val = len | USB_BUF_CTRL_AVAIL;

    if (ep_is_tx(ep)) {
        // Need to copy the data from the user buffer to the usb memory
        memcpy((void *) ep->data_buffer, (void *) buf, len);
        // Mark as full
        val |= USB_BUF_CTRL_FULL;
    }

    // Set pid and flip for next transfer
    val |= ep->next_pid ? USB_BUF_CTRL_DATA1_PID : USB_BUF_CTRL_DATA0_PID;
    ep->next_pid ^= 1u;

    *ep->buffer_control = val;
}

/**
 * @brief Send device descriptor to host
 *
 */
void usb_handle_device_descriptor(void) {
    const struct usb_device_descriptor *d = dev_config.device_descriptor;
    // EP0 in
    struct usb_endpoint_configuration *ep = usb_get_endpoint_configuration(EP0_IN_ADDR);
    // Always respond with pid 1
    ep->next_pid = 1;
    usb_start_transfer(ep, (uint8_t *) d, sizeof(struct usb_device_descriptor));
}

/**
 * @brief Send the configuration descriptor (and potentially the configuration and endpoint descriptors) to the host.
 *
 * @param pkt, the setup packet received from the host.
 */
void usb_handle_config_descriptor(volatile struct usb_setup_packet *pkt) {
    uint8_t *buf = &ep0_buf[0];

    // First request will want just the config descriptor
    const struct usb_configuration_descriptor *d = dev_config.config_descriptor;
    memcpy((void *) buf, d, sizeof(struct usb_configuration_descriptor));
    buf += sizeof(struct usb_configuration_descriptor);

    // If we more than just the config descriptor copy it all
    if (pkt->wLength >= d->wTotalLength) {
        memcpy((void *) buf, dev_config.interface_descriptor, sizeof(struct usb_interface_descriptor));
        buf += sizeof(struct usb_interface_descriptor);
        const struct usb_endpoint_configuration *ep = dev_config.endpoints;

        // Copy all the endpoint descriptors starting from EP1
        for (uint i = 2; i < USB_NUM_ENDPOINTS; i++) {
            if (ep[i].descriptor) {
                memcpy((void *) buf, ep[i].descriptor, sizeof(struct usb_endpoint_descriptor));
                buf += sizeof(struct usb_endpoint_descriptor);
            }
        }

    }

    // Send data
    // Get len by working out end of buffer subtract start of buffer
    uint32_t len = (uint32_t) buf - (uint32_t) &ep0_buf[0];
    usb_start_transfer(usb_get_endpoint_configuration(EP0_IN_ADDR), &ep0_buf[0], len);
}

/**
 * @brief Handle a BUS RESET from the host by setting the device address back to 0.
 *
 */
void usb_bus_reset(void) {
    // Set address back to 0
    dev_addr = 0;
    should_set_address = false;
    usb_hw->dev_addr_ctrl = 0;
    usb_configured = false;
}

/**
 * @brief Send the requested string descriptor to the host.
 *
 * @param pkt, the setup packet from the host.
 */
void usb_handle_string_descriptor(volatile struct usb_setup_packet *pkt) {
    uint8_t i = pkt->wValue & 0xff;
    uint8_t len = 0;

    if (i == 0) {
        len = 4;
        memcpy(&ep0_buf[0], dev_config.lang_descriptor, len);
    } else {
        // Prepare fills in ep0_buf
        len = usb_prepare_string_descriptor(dev_config.descriptor_strings[i - 1]);
    }

    usb_start_transfer(usb_get_endpoint_configuration(EP0_IN_ADDR), &ep0_buf[0], len);
}

/**
 * @brief Sends a zero length status packet back to the host.
 */
void usb_acknowledge_out_request(void) {
    usb_start_transfer(usb_get_endpoint_configuration(EP0_IN_ADDR), NULL, 0);
}

/**
 * @brief Handles a SET_ADDR request from the host. The actual setting of the device address in
 * hardware is done in ep0_in_handler. This is because we have to acknowledge the request first
 * as a device with address zero.
 *
 * @param pkt, the setup packet from the host.
 */
void usb_set_device_address(volatile struct usb_setup_packet *pkt) {
    // Set address is a bit of a strange case because we have to send a 0 length status packet first with
    // address 0
    dev_addr = (pkt->wValue & 0xff);
    printf("Set address %d\r\n", dev_addr);
    // Will set address in the callback phase
    should_set_address = true;
    usb_acknowledge_out_request();
}

/**
 * @brief Handles a SET_CONFIGRUATION request from the host. Assumes one configuration so simply
 * sends a zero length status packet back to the host.
 *
 * @param pkt, the setup packet from the host.
 */
void usb_set_device_configuration(volatile struct usb_setup_packet *pkt) {
    // Only one configuration so just acknowledge the request
    printf("Device Enumerated\r\n");
    usb_acknowledge_out_request();
    usb_configured = true;
}
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
int main(void) {

	// set the sys clock to 120mhz
	set_sys_clock_khz(120000, true);

	// use the button signal for debug uart tx
	gpio_set_function(KEKS_BTN, GPIO_FUNC_UART);

	stdio_init_all();

	printf("Keks initializing ...\n");

	printf("enable clock output ...\n");
	clock_gpio_init(KEKS_CLKOUT, CLOCKS_CLK_GPOUT0_CTRL_AUXSRC_VALUE_CLK_USB, 1);

	printf("usb_device_init ...\n");
	usb_device_init();

	printf("starting second core ...\n");
	multicore_reset_core1();
	multicore_launch_core1(core1_main);

	init_keks();
//	ice40_reset();

	int usb_started = 0;
	bool kfc_prev = 0;
	rpmem_ctr = 0;

	// Everything is interrupt driven so just loop here
	while (1) {

		tight_loop_contents();

      if (usb_configured && !usb_started) {
         usb_start_transfer(usb_get_endpoint_configuration(EP1_OUT_ADDR),
            NULL, 64);
         usb_started = 1;
      }

		int cdone = gpio_get(ICE40_CDONE);
		if (cdone && cdone != kfc_prev) {
			init_keks_postconf();
		}

		kfc_prev = cdone;

		if (usb_host_device != NULL) {

			for (int dev_idx = 0; dev_idx < PIO_USB_DEVICE_CNT; dev_idx++) {
				usb_device_t *device = &usb_host_device[dev_idx];

				if (!device->connected) {
					continue;
				}

				// Print received packet to EPs
				for (int ep_idx = 0; ep_idx < PIO_USB_DEV_EP_CNT; ep_idx++) {

					endpoint_t *ep = pio_usb_get_endpoint(device, ep_idx);

					if (ep == NULL) {
						break;
					}

					uint8_t rpt[64];
					int len = pio_usb_get_in_data(ep, rpt, sizeof(rpt));

					if (len > 0) {

						rpt[15] = dev_idx;

				//		for (int xx = 0; xx < 16; xx++) {
				//			printf("%02x ", rpt[xx]);
				//		}
				//		printf("\n");

				//		printf("X %02x %02x %02x %02x %02x\n",
				//			rpt[0], rpt[1], rpt[2], rpt[3], rpt[4]);

						// send the report if it's changed
						if (dev_idx == 0 && rptcmp(rpt, rpt_l, 16)) {

						//	printf("L %02x %02x %02x %02x %02x\n",
						//		rpt[0], rpt[1], rpt[2], rpt[3], rpt[4]);

							pio_spi_master_write8_blocking(SPI_MASTER_TX_PIO,
								SPI_MASTER_TX_SM, rpt, 16);

						}

						if (dev_idx == 1 && rptcmp(rpt, rpt_r, 16)) {

						//	printf("R %02x %02x %02x %02x %02x\n",
						//		rpt[0], rpt[1], rpt[2], rpt[3], rpt[4]);

							pio_spi_master_write8_blocking(SPI_MASTER_TX_PIO,
								SPI_MASTER_TX_SM, rpt, 16);

						}

						if (dev_idx == 0) {
							memcpy(rpt_l, rpt, 64);
						}
						if (dev_idx == 1) {
							memcpy(rpt_r, rpt, 64);
						}

					}
				}
			}
		}

/*
		if (keks_fpga_configured) {

			if (!pio_sm_is_rx_fifo_empty(SPI_SLAVE_RX_PIO, SPI_SLAVE_RX_SM)) {

				if (rpmem_ctr > 7) {
					printf("rpmem overflow!\n");
					rpmem_ctr = 0;
				}

				rpmem_in[rpmem_ctr] = pio_sm_get_blocking(SPI_SLAVE_RX_PIO,
					SPI_SLAVE_RX_SM);

				if (rpmem_ctr == 3) {

					printf("got rpmem cmd %.2x adr: %.2x %.2x %.2x\n",
						rpmem_in[0], rpmem_in[1], rpmem_in[2], rpmem_in[3] );

					if (rpmem_in[0] == 0x03) {	// READ

						printf("reading from %x %x %x\n",
							rpmem_in[1], rpmem_in[2], rpmem_in[3]);

						rpmem_out[0] = 0x55;
						rpmem_out[1] = 0x66;
						rpmem_out[2] = 0x77;
						rpmem_out[3] = 0x88;

						pio_spi_slave_write8_blocking(SPI_SLAVE_TX_PIO,
							SPI_SLAVE_TX_SM, rpmem_out, 4);

					}

					gpio_put(KEKS_HOLD, 0);	// disable read hold

				}

				if (rpmem_ctr == 7) {

					if (rpmem_in[0] == 0x02) {	// WRITE

						printf("writing: %x %x %x %x to %x %x %x\n",
							rpmem_in[4], rpmem_in[5], rpmem_in[6], rpmem_in[7],
							rpmem_in[1], rpmem_in[2], rpmem_in[3]);

					}

					rpmem_ctr = 0;

				} else {

					++rpmem_ctr;

				}

			}

		}
*/

	}

	return 0;

}

// SPI slave interface


void gpio_int(uint gpio, uint32_t events) {

	if ((events & GPIO_IRQ_EDGE_FALL) == GPIO_IRQ_EDGE_FALL) {

//		printf("gpio_int: %i\n", gpio);

//		if (gpio == KEKS_BTN) {
//			printf("button pressed!\n");
//		}

/*
		if (gpio == MUSLI_SPI_CSN_PIN) {
//			printf("gpio_fall: cspi_ss\n");
			rpmem_ctr = 0;
			gpio_put(KEKS_HOLD, 1);	// enable read hold
 			pio_sm_restart(SPI_SLAVE_RX_PIO, SPI_SLAVE_RX_SM);
 			pio_sm_restart(SPI_SLAVE_TX_PIO, SPI_SLAVE_TX_SM);
		}
*/

	}
}

// use the second core for the USB host controller

void core1_main() {

   sleep_ms(10);

   // To run USB SOF interrupt in core1, create alarm pool in core1.
   static pio_usb_configuration_t config = PIO_USB_DEFAULT_CONFIG;
   config.alarm_pool = (void*)alarm_pool_create(2, 1);
   usb_host_device = pio_usb_host_init(&config);

   // Call pio_usb_host_add_port to use multi port
   const uint8_t pin_dp2 = 13;
   pio_usb_host_add_port(pin_dp2);

	// set up SPI slave PIO state machines
	uint offset_rx = pio_add_program(SPI_SLAVE_RX_PIO, &spi_slave_rx_program);
	spi_slave_rx_program_init(SPI_SLAVE_RX_PIO, SPI_SLAVE_RX_SM, offset_rx,
		MUSLI_SPI_SCK_PIN, MUSLI_SPI_RX_PIN);

	uint offset_tx = pio_add_program(SPI_SLAVE_TX_PIO, &spi_slave_tx_program);
	spi_slave_tx_program_init(SPI_SLAVE_TX_PIO, SPI_SLAVE_TX_SM, offset_tx,
		MUSLI_SPI_SCK_PIN, MUSLI_SPI_TX_PIN);

	uint offset_mtx = pio_add_program(SPI_MASTER_TX_PIO, &spi_master_tx_program);
	spi_master_tx_program_init(SPI_MASTER_TX_PIO, SPI_MASTER_TX_SM, offset_mtx,
		KEKS_INT, KEKS_TX);

   while (true) {
      pio_usb_host_task();
   }

}

void __time_critical_func(pio_spi_slave_write8_blocking)(PIO pio, uint sm, const uint8_t *src, size_t len) {
    size_t tx_remain = len;
    // Do 8 bit accesses on FIFO, so that write data is byte-replicated. This
    // gets us the left-justification for free (for MSB-first shift-out)
    io_rw_8 *txfifo = (io_rw_8 *) &pio->txf[sm];
    while (tx_remain) {
        if (tx_remain && !pio_sm_is_tx_fifo_full(pio, sm)) {
            *txfifo = *src++;
            --tx_remain;
        }
    }
}

void __time_critical_func(pio_spi_master_write8_blocking)(PIO pio, uint sm, const uint8_t *src, size_t len) {
    size_t tx_remain = len;
    // Do 8 bit accesses on FIFO, so that write data is byte-replicated. This
    // gets us the left-justification for free (for MSB-first shift-out)
    io_rw_8 *txfifo = (io_rw_8 *) &pio->txf[sm];
    while (tx_remain) {
        if (tx_remain && !pio_sm_is_tx_fifo_full(pio, sm)) {
            *txfifo = *src++;
            --tx_remain;
        }
    }
}

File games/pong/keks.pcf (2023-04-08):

# Keks V1
# -------

set_io CLK_100		F7
set_io CLK_RP		K9

set_io LED			A5
set_io BTN			A6

# PMOD A
set_io PMOD_A1		A11
set_io PMOD_A2		B13
set_io PMOD_A3		A15
set_io PMOD_A4		A16
set_io PMOD_A7		B12
set_io PMOD_A8		B14
set_io PMOD_A9		B15
set_io PMOD_A10	C14

# KEKS CART on PMODA
set_io CART_SS		A11
set_io CART_MOSI	B13
set_io CART_MISO	A15
set_io CART_SCK	A16

# PMODB
set_io PMOD_B1		M12
set_io PMOD_B2		T16
set_io PMOD_B3		R10
set_io PMOD_B4		P10
set_io PMOD_B7		R16
set_io PMOD_B8		T15
set_io PMOD_B9		P13
set_io PMOD_B10	T11

# USB-UART on PMODB
set_io UART0_RTS  M12
set_io UART0_RX   T16
set_io UART0_TX   R10
set_io UART0_CTS  P10

# RP2040
set_io RP_TX		L6
set_io RP_RX		L7
set_io RP_HOLD		L7
set_io RP_INT		D9

# SRAM
set_io SRAM_A0		C5
set_io SRAM_A1		C6
set_io SRAM_A2		C7
set_io SRAM_A3		B6
set_io SRAM_A4		B5
set_io SRAM_A5		B4
set_io SRAM_A6		B3
set_io SRAM_A7		A1
set_io SRAM_A8		C10
set_io SRAM_A9		C11
set_io SRAM_A10	A10
set_io SRAM_A11	B11
set_io SRAM_A12	B9
set_io SRAM_A13	A9
set_io SRAM_A14	B10
set_io SRAM_A15	C9
set_io SRAM_A16	A7
set_io SRAM_A17	A2

set_io SRAM0_D0	J5
set_io SRAM0_D1	H5
set_io SRAM0_D2	H6
set_io SRAM0_D3	G5
set_io SRAM0_D4	G4
set_io SRAM0_D5	F1
set_io SRAM0_D6	E2
set_io SRAM0_D7	F2
set_io SRAM0_D8	F5
set_io SRAM0_D9	D1
set_io SRAM0_D10	E3
set_io SRAM0_D11	D2
set_io SRAM0_D12	C1
set_io SRAM0_D13	B1
set_io SRAM0_D14	C2
set_io SRAM0_D15	B2

set_io SRAM0_CE	G3
set_io SRAM0_OE	F3
set_io SRAM0_WE	G2
set_io SRAM0_UB	E4
set_io SRAM0_LB	F4

set_io SRAM1_D0	R1
set_io SRAM1_D1	M3
set_io SRAM1_D2	M4
set_io SRAM1_D3	N4
set_io SRAM1_D4	K4
set_io SRAM1_D5	K5
set_io SRAM1_D6	L5
set_io SRAM1_D7	M5
set_io SRAM1_D8	M1
set_io SRAM1_D9	L1
set_io SRAM1_D10	M2
set_io SRAM1_D11	K1
set_io SRAM1_D12	K3
set_io SRAM1_D13	J2
set_io SRAM1_D14	J1
set_io SRAM1_D15	H1

set_io SRAM1_CE	P2
set_io SRAM1_OE	P1
set_io SRAM1_WE	M6
set_io SRAM1_UB	N3
set_io SRAM1_LB	N2

# OPI PSRAM
set_io HRAM_ADQ0	L16
set_io HRAM_ADQ1	K16
set_io HRAM_ADQ2	K14
set_io HRAM_ADQ3	M15
set_io HRAM_ADQ4	P16
set_io HRAM_ADQ5	N16
set_io HRAM_ADQ6	M16
set_io HRAM_ADQ7	K15
set_io HRAM_DQ8	J14
set_io HRAM_DQ9	J16
set_io HRAM_DQ10	E14
set_io HRAM_DQ11	D16
set_io HRAM_DQ12	D15
set_io HRAM_DQ13	F14
set_io HRAM_DQ14	F15
set_io HRAM_DQ15	L14
set_io HRAM_CE		E16
set_io HRAM_CK		J15
set_io HRAM_DQS0	K13
set_io HRAM_DQS1	H14

# DDMI
set_io DDMI_D0_N	T7
set_io DDMI_D1_N	T9
set_io DDMI_D2_N	T13
set_io DDMI_CK_N	T5
set_io DDMI_D0_P	T8
set_io DDMI_D1_P	T10
set_io DDMI_D2_P	T14
set_io DDMI_CK_P	T6

# COMPOSITE VIDEO
set_io COMP_D0		T1
set_io COMP_D1		R2
set_io COMP_D2		T2
set_io COMP_D3		R3

# AUDIO
set_io AUDIO_L		T3
set_io AUDIO_R		R4

# CONFIG SPI
set_io SPI_SS		R12
set_io SPI_SCK		R11
set_io SPI_MISO	P11	# CSPI_SI
set_io SPI_MOSI	P12	# CSPI_SO

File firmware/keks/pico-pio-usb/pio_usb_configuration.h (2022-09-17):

#pragma once

typedef enum {
  PIO_USB_PINOUT_DPDM = 0,  // DM = DP +1
  PIO_USB_PINOUT_DMDP,      // DM = DP -1
} PIO_USB_PINOUT;

typedef struct {
  uint8_t pin_dp;
  PIO_USB_PINOUT pinout;
  uint8_t pio_tx_num;
  uint8_t sm_tx;
  uint8_t tx_ch;
  uint8_t pio_rx_num;
  uint8_t sm_rx;
  uint8_t sm_eop;
  void* alarm_pool;
  int8_t debug_pin_rx;
  int8_t debug_pin_eop;
} pio_usb_configuration_t;

#ifndef PIO_USB_DP_PIN_DEFAULT
#define PIO_USB_DP_PIN_DEFAULT 0
#endif

#ifndef PIO_USB_PINOUT_DEFAULT
#define PIO_USB_PINOUT_DEFAULT PIO_USB_PINOUT_DPDM
#endif

//#define PIO_USB_DM_PIN_DEFAULT (PIO_USB_DP_PIN_DEFAULT - 1)

#define PIO_USB_TX_DEFAULT 0
#define PIO_SM_USB_TX_DEFAULT 0
#define PIO_USB_DMA_TX_DEFAULT 0

#define PIO_USB_RX_DEFAULT 1
#define PIO_SM_USB_RX_DEFAULT 0
#define PIO_SM_USB_EOP_DEFAULT 1

#define PIO_USB_DEBUG_PIN_NONE (-1)

#define PIO_USB_DEFAULT_CONFIG                                             \
  {                                                                        \
    PIO_USB_DP_PIN_DEFAULT, PIO_USB_PINOUT_DEFAULT, PIO_USB_TX_DEFAULT,    \
        PIO_SM_USB_TX_DEFAULT, PIO_USB_DMA_TX_DEFAULT, PIO_USB_RX_DEFAULT, \
        PIO_SM_USB_RX_DEFAULT, PIO_SM_USB_EOP_DEFAULT, NULL,               \
        PIO_USB_DEBUG_PIN_NONE, PIO_USB_DEBUG_PIN_NONE                     \
  }

#define PIO_USB_EP_POOL_CNT 32
#define PIO_USB_DEV_EP_CNT 16
#define PIO_USB_DEVICE_CNT 4
#define PIO_USB_HUB_PORT_CNT 8
#define PIO_USB_ROOT_PORT_CNT 2

#define PIO_USB_EP_SIZE 64

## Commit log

2023-04-08 add case
    [keks.scad, keks_cart.scad]
2023-05-10 add pcb
    [keks.kicad_pcb, keks.kicad_sch]

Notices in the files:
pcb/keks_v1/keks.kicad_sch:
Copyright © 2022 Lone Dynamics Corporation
